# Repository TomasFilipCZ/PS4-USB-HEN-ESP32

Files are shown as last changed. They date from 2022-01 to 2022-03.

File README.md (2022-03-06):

<h1 align="center">PS4 USB Flash Emulator with ESP32-S2 (PS4-USB-ESP32)</h1>

<p>Small electronic board to support automatic loading HEN in PS4 with ESP32. Project using method discovered on PS4 Firmware 9.00, where user need manually plug USB flash drive in right time to load HEN. 

Together with  ESP32-S2 as WebServer will PS4-USB-ESP32 emulate USB Flash drive, causing automatic loading HEN in desired time without user interaction.

Project is modification of "PS4 Server 9.00" and "ESP8266 Control device", aim is to share design data of small PCB and firmware for the ESP32-S2 to create device for wide  usage of automatic loading and implement basic electronic protection for PS4.

Differents to standard market ESP32-S2 eval kits are:
- ESP32-S2 plan to use is in version with 16MBytes (but can be use ESP32-S2 with 4Mbytes)
- MicroSD card in 4bit mode (can be configured to SPI mode)
- Direct USB OTG connection to emulate Flash Drive
- ESD protections and RGB LED 
 </p>

<i>Status</i>
<b> 06.03.2022 - you can buy first protypes on  [ebay](https://www.ebay.de/itm/165370662367)</b>

## Project requirements
- Micro SD card (prefered 4Gbyte, standard SDHC formated as FAT32)
- USB 2.0 data cable ( is recommend to not exceed length of 1.8M )
- Binary loader for the ESP32-S2

## Links
PS4-USB-HEN32 needs firmware to run WebServer with DHCP/DNS service, you can programm device either by 
 - [Karo](https://karo218.ir/espweb/ "Karo ESP programming method") or 
 - [XHOST-PRO ](https://t.co/l7LI6YW8ns "XHOST-Pro programming method") 

To program board, you need 
1. Hhold Reset Button,
2. Press Boot button and 
3. release Reset Button and release Boot button

(Serial ports and USB-ESP-S2 device is appear in the system)

## Setup
- Plug PS4-USB-HEN32 with micro USB cable to PS4. Due Webserver/DNS capability  web page with HEN  can be access through 'User Guide/Helpful Info' in PS4  <i>(required successful Wifi connection to PS4-USB-HEN32, password '12345678'</i> )

## Pictures

3D Picture of PCBA 

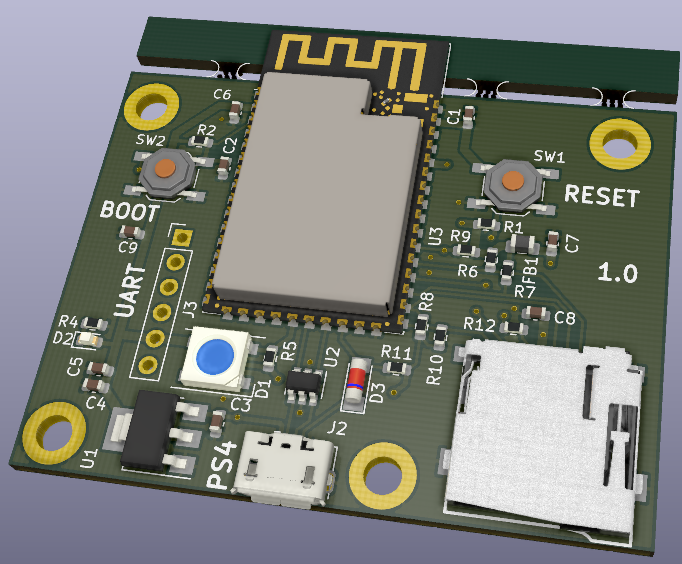
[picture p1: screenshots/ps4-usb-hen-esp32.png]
PS4-USB-HEN32


## Project structure

- PCB Design data are developed in KiCad 5.1.10
- directory <b>bom</b> contains JLCPCB compatible BOM,after product check later full BOM 
- directory <b>gerber</b> contains gerbers files with pick-up place file. Components are located only in TOP layer. 
- directory <b>libs </b> contains project specific  library

note:   PS4-USB-ESP32 project used module ESP32-S2, severals version may be supported
 - <b>ESP32-S2-WROVER(16MB) - preferred </b>
 - ESP32-S2-WROOM or ESP32-S2-WROVER (4MB)

## Future Updates

- [X] Figure out, if 4-bit SD card mode is working, check the design (but not EMMC_SD library, not supported by ESP32-S2)
- [X] Create STEP/STL Model of Plastic BOX to be able printed in 3D Printer
- [X]  Waiting for Delivering PCB to test all complete designs

##Update in 1.1 Version
- Use transistor level shifter for RGB LED. RGB led is now powered from 5V to be brighter. 
- PCB will goes to black and thickness to 1.0mm therefore CAD design needs to be fine tune 

## Author

**Tomas Filip**

- [Profile](https://github.com/TomasFilipCZ "Tomas Filip on GitHub")
- [Join us on Discord](https://discord.gg/DWephJvzwR "Discord Server")

## 🤝 Support

Contributions, issues, and feature requests are welcome!

if you like this project, stay tuned !

<i>Special thanks: Karo, ChendoChap, stooged, xps3riments for their work and thanks to all community helper and developer on PS scene.  It's really fun...</i>

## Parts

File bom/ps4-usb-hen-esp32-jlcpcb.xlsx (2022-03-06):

Comment | Designator | Footprint | LCSC Part #
100nF | C1, C2, C3, C4, C6, C8,C9 | Capacitor_SMD:C_0603_1608Metric | C14663
10uF_10V | C5, C7 | Capacitor_SMD:C_0603_1608Metric | C19702
WS2812B | D1 | LED_SMD:LED_WS2812B_PLCC4_5.0x5.0mm_P3.2mm | C139127
D_LED_0603_Red | D2 | LED_SMD:LED_0603_1608Metric | C2286
LL4148 | D3 | Diode_SMD:D_MiniMELF | C9808
Ferrite_Bead_Small | FB1 | Inductor_SMD:L_0805_2012Metric | C1017
Micro_SD_Card | J1 | esp32-usb:GCT-MEM2055-00-190-01-A | C393941
USB_B_Micro | J2 | esp32-usb:USB_Micro-Jing Extension | C10418
10K | R1, R2, R3, R5, R6, R7, R8, R9, R10, R11 | R_0603_1608Metric | C25804
330R | R4 | R_0603_1608Metric | C23138
22R | R12 | R_0603_1608Metric | C23345
SW_Push | SW1, SW2 | SW_SPST_TL3342 | C318884
AMS1117-3.3 | U1 | Package_TO_SOT_SMD:SOT-223-3_TabPin2 | C6186
SRV05-4 | U2 | SOT-23-6 | C85364
ESP32-S2-WROVER | U3 | ESP32-S2-WROVER | C701333
2N7002 | Q1 | SOT-23 | C8545

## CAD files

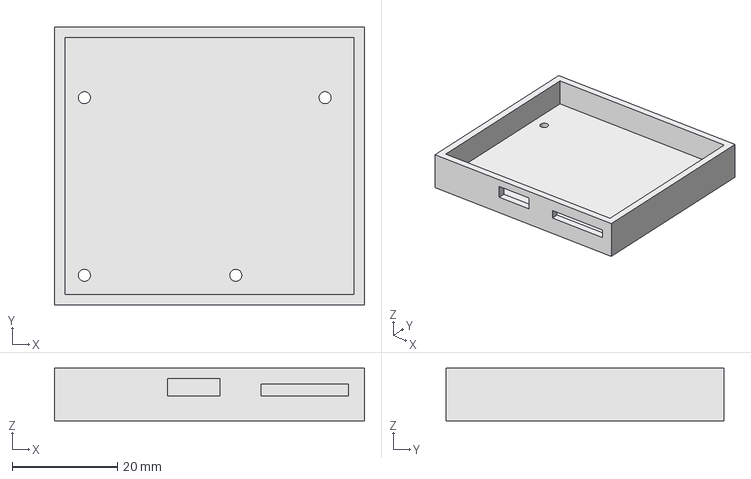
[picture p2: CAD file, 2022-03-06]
cad/box-bottom-esp32.FCStd
59.0 x 53.0 x 10.0 mm

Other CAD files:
cad/box-bottom-esp32.stl

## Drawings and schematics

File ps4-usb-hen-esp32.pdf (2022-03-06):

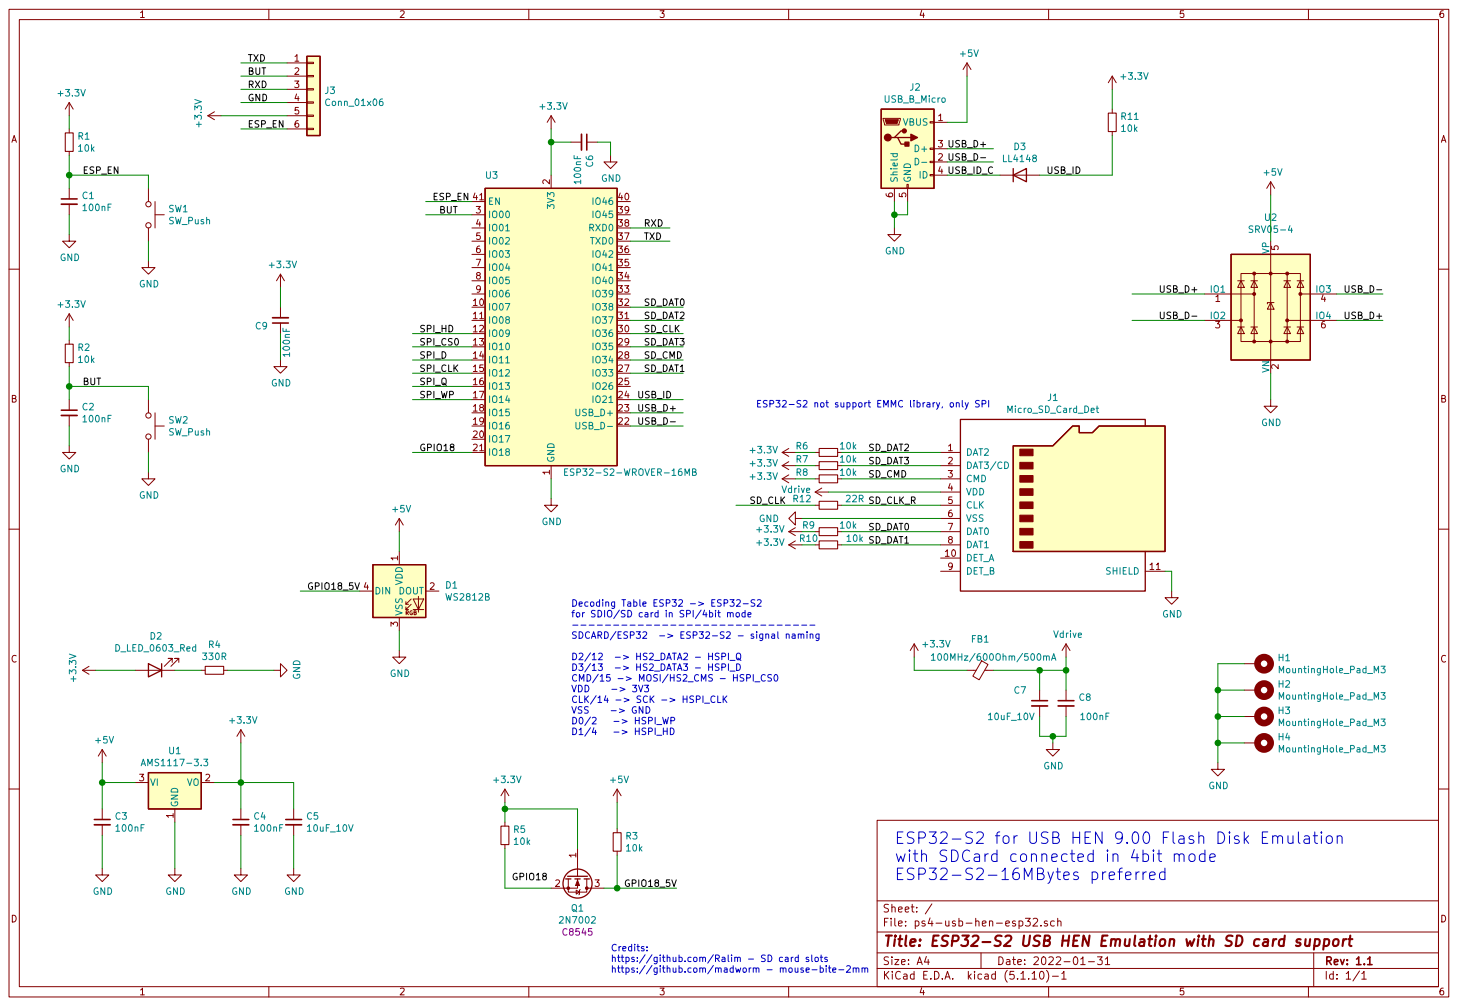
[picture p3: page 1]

ESP32-S2 not support EMMC library, only SPI

Decoding Table ESP32 -> ESP32-S2
for SDIO/SD card in SPI/4bit mode
------------------------------ SDCARD/ESP32 -> ESP32-S2 - signal naming D2/12 -> HS2_DATA2 - HSPI_Q

D3/13 -> HS2_DATA3 - HSPI_D
CMD/15 -> MOSI/HS2_CMS - HSPI_CS0 VDD -> 3V3 CLK/14 -> SCK -> HSPI_CLK VSS -> GND

ESP32-S2 for USB HEN 9.00 Flash Disk Emulation
with SDCard connected in 4bit mode
ESP32-S2-16MBytes preferred

File: ps4-usb-hen-esp32.sch Sheet: /
Id: 1/1 Title: ESP32-S2 USB HEN Emulation with SD card support

Credits: https://github.com/Ralim - SD card slots

https://github.com/madworm - mouse-bite-2mm

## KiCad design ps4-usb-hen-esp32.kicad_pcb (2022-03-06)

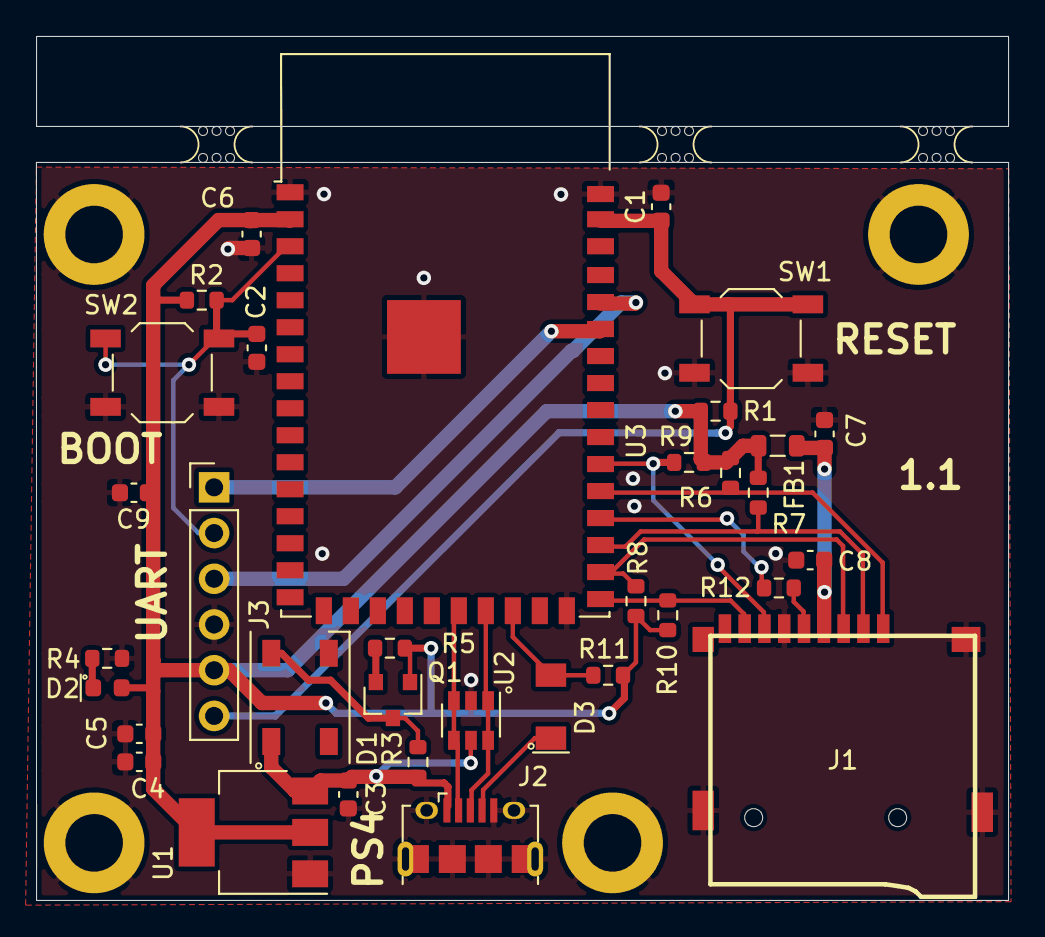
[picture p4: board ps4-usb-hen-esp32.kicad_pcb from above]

Board: 2 copper layers, 54.0 x 48.0 mm, 41 parts (0 on the bottom side), 22 nets.

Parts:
C1, C2, C3, C4, C6, C8, C9: 100nF; C_0603_1608Metric
C5, C7: 10uF_10V; C_0603_1608Metric
D1: WS2812B; LED_WS2812B_PLCC4_5.0x5.0mm_P3.2mm
D2: D_LED_0603_Red; LED_0603_1608Metric
D3: LL4148; D_MiniMELF
FB1: 100MHz/600Ohm/500mA; L_0805_2012Metric
H1, H2, H3, H4: MountingHole_Pad_M3; MountingHole_3.2mm_M3_DIN965_Pad
J1: Micro_SD_Card_Det; GCT-MEM2055-00-190-01-A
J2: USB_B_Micro; USB_Micro-Jing Extension
J3: Conn_01x06; PinHeader_1x06_P2.54mm_Vertical
Q1: 2N7002; SOT-23
R1, R2, R3, R5, R6, R7, R8, R9, R10, R11: 10k; R_0603_1608Metric
R4: 330R; R_0603_1608Metric
R12: 22R; R_0603_1608Metric
SW1, SW2: SW_Push; SW_SPST_TL3342
U1: AMS1117-3.3; SOT-223-3_TabPin2
U2: SRV05-4; SOT-23-6
U3: ESP32-S2-WROVER-16MB; ESP32-S2-WROVER
mouse-bite-2mm-slot, mouse-bite-2mm-slot#2, mouse-bite-2mm-slot#3: VAL**; mouse-bite-2mm-slot

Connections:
+3V3: C4.1, C5.1, C6.2, C9.2, D2.2, FB1.2, J3.5, Q1.1, R1.1, R2.1, R5.1, R6.2, R7.2, R8.2, R9.2, R10.2, R11.1, U1.2, U3.2
+5V: C3.1, D1.1, J2.1, R3.1, U1.3, U2.5
/BUT: C2.1, J3.2, R2.2, SW2.1, U3.3
/ESP_EN: C1.1, J3.6, R1.2, SW1.1, U3.41
/GPIO18_5V: D1.4, Q1.3, R3.2
/RXD: J3.3, U3.38
/SD_CLK: R12.2, U3.30
/SD_CLK_R: J1.5, R12.1
/SD_CMD: J1.3, R8.1, U3.28
/SD_DAT0: J1.7, R9.1, U3.32
/SD_DAT1: J1.8, R10.1, U3.27
/SD_DAT2: J1.1, R6.1, U3.31
/SD_DAT3: J1.2, R7.1, U3.29
/TXD: J3.1, U3.37
/USB_D+: J2.3, U2.1, U2.6, U3.23
/USB_D-: J2.2, U2.3, U2.4, U3.22
/USB_ID: D3.2, R11.2, U3.24
/USB_ID_C: D3.1, J2.4
GND: C1.2, C2.2, C3.2, C4.2, C5.2, C6.1, C7.2, C8.2, C9.1, D1.3, H1.1, H2.1, H3.1, H4.1, J1.6, J1.11, J2.5, J2.6, J3.4, R4.1, SW1.2, SW2.2, U1.1, U2.2, U3.1, U3.26, U3.42, U3.43
unnamed: D2.1, R4.2
unnamed: Q1.2, R5.2
Vdrive: C7.1, C8.1, FB1.1, J1.4

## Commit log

2022-01-31 first issue
    [ps4-usb-hen-esp32-jlcpcb.xlsx, ps4-usb-hen-esp32.kicad_pcb, ps4-usb-hen-esp32.sch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]
2022-03-06 change RGB LED to 5V, add level shifter, change thickness of PCB to 1.0mm, add simple box with FreeCad, update readme
    [box-bottom-esp32.FCStd, box-bottom-esp32.stl, ps4-usb-hen-esp32-jlcpcb.xlsx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]
